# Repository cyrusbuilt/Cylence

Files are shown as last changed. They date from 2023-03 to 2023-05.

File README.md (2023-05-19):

# Cylence


IoT doorbell killswitch (ESP8266 Arduino - Based)

## Synopsis

I have dogs. LOUD dogs. Also, I work from home. Whenever someone comes to my door and rings my doorbell, my dogs go absolutely bonkers and bark their faces off. I've tried training them not to, but to no avail. The problem is, every time I'm in a meeting or a call and my dogs start barking their faces off, it's difficult to get them to stop. So I decided I needed a way to temporarily *mute* my door bell. A sort of "killswitch", if you will. Seems simple enough... Just put a toggle switch or light switch betwen in the power source and the bell transformer. But my bell transformer is in the basement. And what if I forget to turn it back on? Like so many of my IoT projects, I decided it would be a lot cooler if I could just do it from my phone, integrate it with the rest of my home automation system and have alerts to let me know if I forgot to turn it back on. So, I decided to design a simple PCB around an ESP8266 and a relay and then integrate it with [OpenHAB](https://www.openhab.org) and [RedQueen](https://github.com/cyrusbuilt/RedQueen) using [MQTT](https://mqtt.org/). When the Cylence is 'active' it closes the relay (wired to Normally-Closed) which disconnects the power to the bell transformer. Then deactivating shuts off the relay allowing the circuit to close again and power the door bell back up. Easy peasy.

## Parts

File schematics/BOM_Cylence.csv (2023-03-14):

ID | Name | Designator | Footprint | Quantity | Manufacturer Part | Manufacturer | Supplier | Supplier Part | Price
1 | ACT | D1 | PKG-LED-5MM-RED | 1 | L-1503EC | KINGBRIGHT | Element14 | 1003201
2 | NET | D2 | LED-GREEN-2.54-5MM-YUN | 1 | 503UOC
3 | 1N4001 | D3 | DIODE-1N4001 | 1
4 | RS-232 PGM / DBG | H1 | HEADER-MALE-2.54_1X6 | 1
5 | M023.5MM | JP1,JP2 | SCREWTERMINAL-3.5MM-2 | 2
6 | G5LE-14_DC3 | K1 | G5LE-14_SPDT | 1
7 | Huzzah ESP8266 Breakout_TT | U1 | HUZZAH 8266 | 1 |  | Adafruit

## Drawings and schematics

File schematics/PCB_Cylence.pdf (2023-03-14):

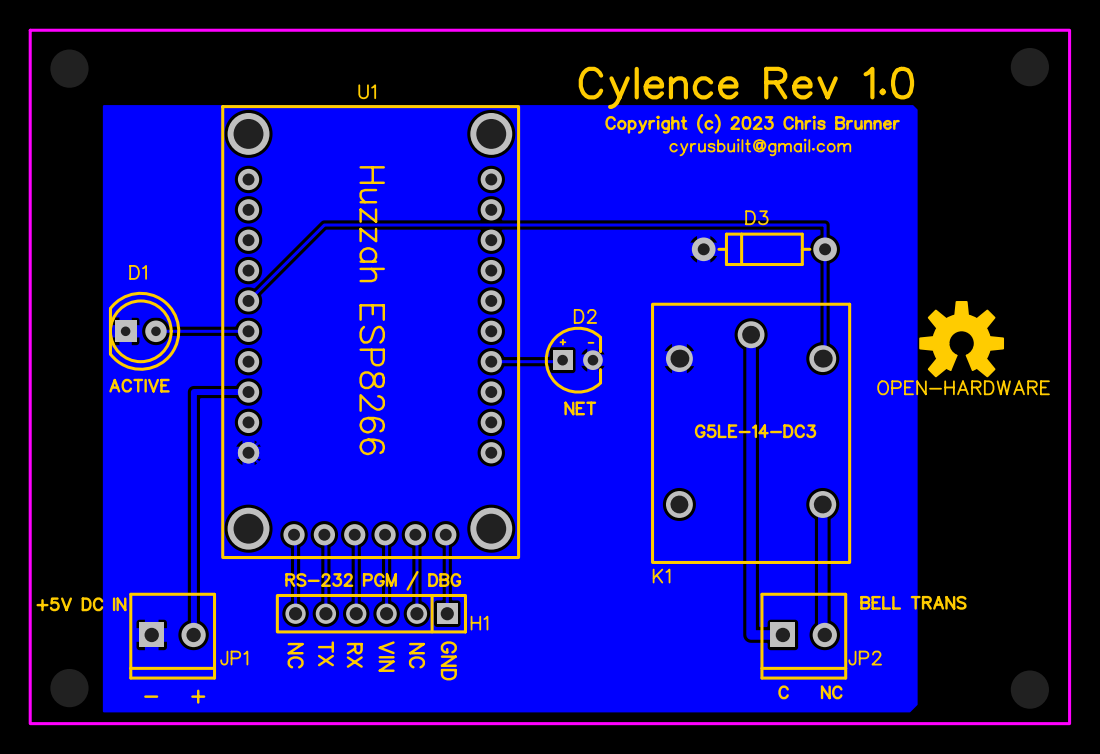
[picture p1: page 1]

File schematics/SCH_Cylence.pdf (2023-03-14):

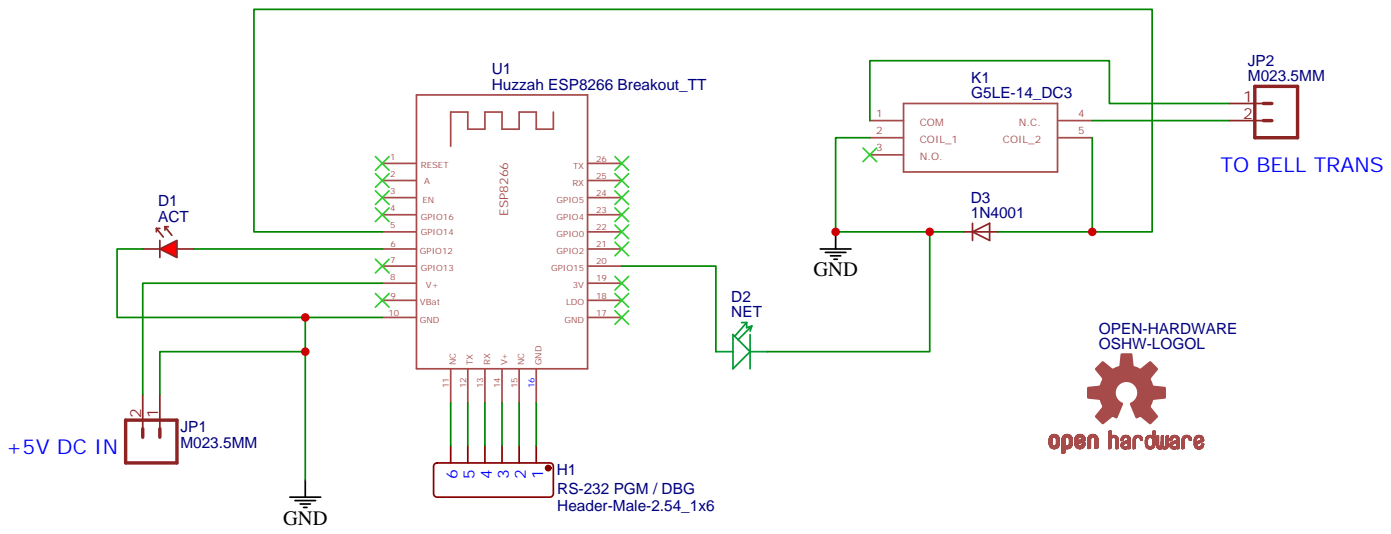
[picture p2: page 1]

Drawn By: Chris Brunner

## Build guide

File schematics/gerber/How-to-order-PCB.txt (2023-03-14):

How to Order PCB

Please refer to:
https://docs.easyeda.com/en/PCB/Order-PCB

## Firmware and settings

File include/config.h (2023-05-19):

#ifndef _CONFIG_H
#define _CONFIG_H

#include <IPAddress.h>

#define DEBUG
#define DEVICE_NAME "CYLENCE"
#define DEVICE_CLASS "cylence"
#define BAUD_RATE 115200
#define ENABLE_OTA
#define ENABLE_MDNS
#define CONFIG_FILE_PATH "/config.json"
#define DEFAULT_SSID "your_ssid_here"
#define DEFAULT_PASSWORD "your_wifi_password"
#define CLOCK_TIMEZONE -4
#define CHECK_WIFI_INTERVAL 30000
#define CLOCK_SYNC_INTERVAL 3600000
#define CHECK_MQTT_INTERVAL 60000 * 5
#define MQTT_TOPIC_STATUS "cylence/status"
#define MQTT_TOPIC_CONTROL "cylence/control"
#define MQTT_TOPIC_DISCOVERY "redqueen/config"
#define MQTT_BROKER "your_mqtt_broker_ip"
#define MQTT_PORT 8883
#ifdef ENABLE_OTA
	#include <ArduinoOTA.h>
	#define OTA_HOST_PORT 8266
	#define OTA_PASSWORD "your_ota_password_here"
#endif
const IPAddress defaultIp(192, 168, 0, 238);
const IPAddress defaultGw(192, 168, 0, 1);
const IPAddress defaultSm(255, 255, 255, 0);
const IPAddress defaultDns(192, 168, 0, 1);

typedef struct {
	// Network stuff
	String hostname;
	String ssid;
	String password;
	IPAddress ip;
	IPAddress gw;
	IPAddress sm;
	IPAddress dns;
	bool useDhcp;

	uint8_t clockTimezone;

	// MQTT stuff
	String mqttTopicStatus;
	String mqttTopicControl;
	String mqttTopicDiscovery;
	String mqttBroker;
	String mqttUsername;
	String mqttPassword;
	uint16_t mqttPort;

	// OTA stuff
	uint16_t otaPort;
	String otaPassword;
} config_t;

#endif

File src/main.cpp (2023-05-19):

#ifndef ESP8266
	#error This firmware is only compatible with ESP8266 controllers.
#endif

#include <Arduino.h>
#include <ESP8266WiFi.h>
#include <WiFiClient.h>
#include <FS.h>
#include <time.h>
#include <TZ.h>
#include "ArduinoJson.h"
#include "Console.h"
#include "ESPCrashMonitor.h"
#include "LED.h"
#include "PubSubClient.h"
#include "Relay.h"
#include "ResetManager.h"
#include "TaskScheduler.h"
#include "TelemetryHelper.h"
#include "config.h"

#define FIRMWARE_VERSION "1.0"

// Pin definitions
#define PIN_LED_ACTIVE 12
#define PIN_LED_NET 15
#define PIN_RELAY 14

// Forward declarations
void onRelayStateChange(RelayInfo *sender);
void onCheckWiFi();
void onCheckMqtt();
void onSyncClock();
void onMqttMessage(char* topic, byte* payload, unsigned int length);

// Global vars
#ifdef ENABLE_MDNS
	#include <ESP8266mDNS.h>
	MDNSResponder mdns;
#endif
WiFiClient wifiClient;
PubSubClient mqttClient(wifiClient);
Task tCheckWiFi(CHECK_WIFI_INTERVAL, TASK_FOREVER, &onCheckWiFi);
Task tCheckMqtt(CHECK_MQTT_INTERVAL, TASK_FOREVER, &onCheckMqtt);
Task tClockSync(CLOCK_SYNC_INTERVAL, TASK_FOREVER, &onSyncClock);
Scheduler taskMan;
HAF_LED activationLED(PIN_LED_ACTIVE, NULL);
HAF_LED netLED(PIN_LED_NET, NULL);
Relay bellRelay(PIN_RELAY, onRelayStateChange, "Killswitch");
config_t config;
bool filesystemMounted = false;
volatile SystemState sysState = SystemState::BOOTING;
volatile bool isActive = false;

String getTimeInfo() {
	time_t now = time(nullptr);
	struct tm *timeinfo = localtime(&now);
	String result = String(asctime(timeinfo));
	result.replace("\n", "");
	return result;
}

void onSyncClock() {
	netLED.on();
	configTime(TZ_America_New_York, "pool.ntp.org");

	Serial.print(F("INIT: Waiting for NTP time sync... "));
	delay(500);
	while (!time(nullptr)) {
		netLED.off();
		ESPCrashMonitor.iAmAlive();
		Serial.print(F("."));
		delay(500);
		netLED.on();
	}

	netLED.off();
	Serial.println(F("DONE"));
	Serial.print(F("INFO: Current time: "));
	Serial.println(getTimeInfo());
}

void publishSystemState() {
	if (!mqttClient.connected()) {
		return;
	}

	netLED.on();

	DynamicJsonDocument doc(400);
	doc["clientId"] = config.hostname.c_str();
	doc["firmwareVersion"] = FIRMWARE_VERSION;
	doc["systemState"] = (uint8_t)sysState;
	doc["silencerState"] = isActive ? "ON" : "OFF";
	doc["lastUpdate"] = getTimeInfo();

	String jsonStr;
	size_t len = serializeJson(doc, jsonStr);
	Serial.print(F("INFO: Publishing system state: "));
	Serial.println(jsonStr);
	if (!mqttClient.publish(config.mqttTopicStatus.c_str(), jsonStr.c_str(), len)) {
		Serial.println(F("ERROR: Failed to publish message."));
	}

	doc.clear();
	netLED.off();
}

void publishDiscoveryPacket() {
	if (!mqttClient.connected()) {
		return;
	}

	DynamicJsonDocument doc(250);
	doc["name"] = config.hostname;
	doc["class"] = DEVICE_CLASS;
	doc["statusTopic"] = config.mqttTopicStatus;
	doc["controlTopic"] = config.mqttTopicControl;

	String jsonStr;
	size_t len = serializeJson(doc, jsonStr);
	Serial.print(F("INFO: Publishing discovery packet: "));
	Serial.println(jsonStr);
	if (!mqttClient.publish(config.mqttTopicDiscovery.c_str(), jsonStr.c_str(), len)) {
		Serial.println(F("ERROR: Failed to publish message."));
	}

	doc.clear();
	netLED.off();
}

void onRelayStateChange(RelayInfo *sender) {
	isActive = sender->state == RelayState::RelayClosed;
	activationLED.setState(isActive ? LEDState::LED_On : LEDState::LED_Off);
	publishSystemState();
}

void resumeNormal() {
	Serial.println(F("INFO: Resuming normal operation..."));
	taskMan.enableAll();
	netLED.off();
	sysState = SystemState::NORMAL;
	publishSystemState();
}

void printNetworkInfo() {
	Serial.print(F("INFO: Local IP: "));
	Serial.println(WiFi.localIP());
	Serial.print(F("INFO: Gateway: "));
	Serial.println(WiFi.gatewayIP());
	Serial.print(F("INFO: Subnet mask: "));
	Serial.println(WiFi.subnetMask());
	Serial.print(F("INFO: DNS server: "));
	Serial.println(WiFi.dnsIP());
	Serial.print(F("INFO: MAC address: "));
	Serial.println(WiFi.macAddress());
	#ifdef DEBUG
		WiFi.printDiag(Serial);
	#endif
}

void reboot() {
	Serial.println(F("INFO: Rebooting..."));
	Serial.flush();
	delay(1000);
	ResetManager.softReset();
}

void saveConfiguration() {
	Serial.print(F("INFO: Saving configuration to: "));
	Serial.print(CONFIG_FILE_PATH);
	Serial.println(F(" ... "));
	if (!filesystemMounted) {
		Serial.println(F("FAIL"));
		Serial.println(F("ERROR: Filesystem not mounted."));
		return;
	}

	DynamicJsonDocument doc(400);
	doc["hostname"] = config.hostname;
	doc["useDhcp"] = config.useDhcp;
	IPAddress ipAddr = IPAddress(config.ip);
	doc["ip"] = ipAddr.toString();
	ipAddr = IPAddress(config.gw);
	doc["gateway"] = ipAddr.toString();
	ipAddr = IPAddress(config.sm);
	doc["subnetmask"] = ipAddr.toString();
	ipAddr = IPAddress(config.dns);
	doc["dnsServer"] = ipAddr.toString();
	doc["wifiSSID"] = config.ssid;
	doc["wifiPassword"] = config.password;
	doc["timezone"] = config.clockTimezone;
	doc["mqttBroker"] = config.mqttBroker;
	doc["mqttPort"] = config.mqttPort;
	doc["mqttControlTopic"] = config.mqttTopicControl;
	doc["mqttStatusTopic"] = config.mqttTopicStatus;
	doc["mqttDiscoveryTopic"] = config.mqttTopicDiscovery;
	doc["mqttUsername"] = config.mqttUsername;
	doc["mqttPassword"] = config.mqttPassword;
	#ifdef ENABLE_OTA
		doc["otaPort"] = config.otaPort;
		doc["otaPassword"] = config.otaPassword;
	#endif

	File configFile = SPIFFS.open(CONFIG_FILE_PATH, "w");
	if (!configFile) {
		Serial.println(F("FAIL"));
		Serial.println(F("ERROR: Failed to open config file for writing."));
		doc.clear();
		return;
	}

	serializeJsonPretty(doc, configFile);
	doc.clear();
	configFile.flush();
	configFile.close();
	Serial.println(F("DONE"));
}

void printWarningAndContinue(const __FlashStringHelper *message) {
	Serial.println();
	Serial.println(message);
	Serial.println(F("INFO: Continuing... "));
}

void setConfigurationDefaults() {
	String chipId = String(ESP.getChipId(), HEX);
	String defHostname = String(DEVICE_NAME) + "_" + chipId;

	config.hostname = defHostname;
	config.ip = defaultIp;
	config.mqttBroker = MQTT_BROKER;
	config.mqttPassword = "";
	config.mqttPort = MQTT_PORT;
	config.mqttTopicControl = MQTT_TOPIC_CONTROL;
	config.mqttTopicStatus = MQTT_TOPIC_STATUS;
	config.mqttTopicDiscovery = MQTT_TOPIC_DISCOVERY;
	config.mqttUsername = "";
	config.password = DEFAULT_PASSWORD;
	config.sm = defaultSm;
	config.ssid = DEFAULT_SSID;
	config.useDhcp = false;
	config.clockTimezone = CLOCK_TIMEZONE;
	config.dns = defaultDns;
	config.gw = defaultGw;
	
	#ifdef ENABLE_OTA
		config.otaPort = config.otaPort;
		config.otaPassword = config.otaPassword;
	#endif
}

void loadConfiguration() {
	memset(&config, 0, sizeof(config));

	Serial.print(F("INFO: Loading config file "));
	Serial.print(CONFIG_FILE_PATH);
	Serial.print(F(" ... "));
	if (!filesystemMounted) {
		Serial.println(F("FAIL"));
		Serial.println(F("ERROR: Filesystem not mounted."));
		return;
	}

	if (!SPIFFS.exists(CONFIG_FILE_PATH)) {
		Serial.println(F("FAIL"));
		Serial.println(F("WARN: Config file does not exist. Creating with default config... "));
		saveConfiguration();
		return;
	}

	File configFile = SPIFFS.open(CONFIG_FILE_PATH, "r");
	if (!configFile) {
		Serial.println(F("FAIL"));
		Serial.println(F("ERROR: Unable to open config file. Using default config."));
		return;
	}

	size_t size = configFile.size();
	uint16_t freeMem = ESP.getMaxFreeBlockSize() - 512;
	if (size > freeMem) {
		Serial.println(F("FAIL"));
		Serial.print(F("ERROR: Not enough free memory to load document. Size = "));
		Serial.print(size);
		Serial.print(F(", Free = "));
		Serial.println(freeMem);
		configFile.close();
		return;
	}

	DynamicJsonDocument doc(freeMem);
	DeserializationError error = deserializeJson(doc, configFile);
	if (error) {
		Serial.println(F("FAIL"));
		Serial.println(F("ERROR: Failed to parse config file to JSON. Using default config."));
		configFile.close();
		return;
	}

	doc.shrinkToFit();
	configFile.close();

	String chipId = String(ESP.getChipId(), HEX);
	String defHostname = String(DEVICE_NAME) + "_" + chipId;

	config.hostname = doc.containsKey("hostname") ? doc["hostname"].as<String>() : defHostname;
	config.useDhcp = doc.containsKey("isDhcp") ? doc["isDhcp"].as<bool>() : false;

	if (doc.containsKey("ip")) {
		if (!config.ip.fromString(doc["ip"].as<String>())) {
			printWarningAndContinue(F("WARN: Invalid IP in configuration. Falling back to factory default."));
		}
	}
	else {
		config.ip = defaultIp;
	}

	if (doc.containsKey("gateway")) {
		if (!config.gw.fromString(doc["gateway"].as<String>())) {
			printWarningAndContinue(F("WARN: Invalid gateway in configuration. Falling back to factory default."));
		}
	}
	else {
		config.gw = defaultGw;
	}

	if (doc.containsKey("subnetmask")) {
		if (!config.sm.fromString(doc["subnetmask"].as<String>())) {
			printWarningAndContinue(F("WARN: Invalid subnet mask in configuration. Falling back to factory default."));
		}
	}
	else {
		config.sm = defaultSm;
	}

	if (doc.containsKey("dnsServer")) {
		if (!config.dns.fromString(doc["dnsServer"].as<String>())) {
			printWarningAndContinue(F("WARN: Invalid DNS IP in configuration. Falling back to factory default."));
		}
	}
	else {
		config.dns = defaultDns;
	}

	config.ssid = doc.containsKey("wifiSSID") ? doc["wifiSSID"].as<String>() : DEFAULT_SSID;
	config.password = doc.containsKey("wifiPassword") ? doc["wifiPassword"].as<String>() : DEFAULT_PASSWORD;
	config.clockTimezone = doc.containsKey("timezone") ? doc["timezone"].as<uint8_t>() : CLOCK_TIMEZONE;
	config.mqttBroker = doc.containsKey("mqttBroker") ? doc["mqttBroker"].as<String>() : MQTT_BROKER;
	config.mqttPort = doc.containsKey("mqttPort") ? doc["mqttPort"].as<int>() : MQTT_PORT;
	config.mqttTopicControl = doc.containsKey("mqttControlTopic") ? doc["mqttControlTopic"].as<String>() : MQTT_TOPIC_CONTROL;
	config.mqttTopicStatus = doc.containsKey("mqttStatusTopic") ? doc["mqttStatusTopic"].as<String>() : MQTT_TOPIC_STATUS;
	config.mqttTopicDiscovery = doc.containsKey("mqttDiscoveryTopic") ? doc["mqttDiscoveryTopic"].as<String>() : MQTT_TOPIC_DISCOVERY;
	config.mqttUsername = doc.containsKey("mqttUsername") ? doc["mqttUsername"].as<String>() : "";
	config.mqttPassword = doc.containsKey("mqttPassword") ? doc["mqttPassword"].as<String>() : "";

	#ifdef ENABLE_OTA
		config.otaPort = doc.containsKey("otaPort") ? doc["otaPort"].as<uint16_t>() : OTA_HOST_PORT;
		config.otaPassword = doc.containsKey("otaPassword") ? doc["otaPassword"].as<String>() : OTA_PASSWORD;
	#endif

	doc.clear();
	Serial.println(F("DONE"));
}

void doFactoryRestore() {
	Serial.println();
	Serial.println(F("Are you sure you wish to restore to factory defaults? (Y/n)"));
	Console.waitForUserInput();

	String str = Console.getInputString();
	str.toLowerCase();
	if (str == "y") {
		Serial.print(F("INFO: Clearing current config... "));
		if (filesystemMounted) {
			if (SPIFFS.remove(CONFIG_FILE_PATH)) {
				Serial.println(F("DONE"));
				Serial.print(F("INFO: Removed file: "));
				Serial.println(CONFIG_FILE_PATH);

				Serial.print(F("INFO: Rebooting in "));
				for (uint8_t i = 5; i >= 1; i--) {
					Serial.print(i);
					Serial.print(F(" "));
					delay(1000);
				}

				reboot();
			}
			else {
				Serial.println(F("FAIL"));
				Serial.println(F("ERROR: Failed to delete configuration file."));
			}
		}
		else {
			Serial.println(F("FAIL"));
			Serial.println(F("ERROR: Filesystem not mounted."));
		}
	}

	Serial.println();
}

void printAvailableNetworks() {
	ESPCrashMonitor.defer();
	Serial.println(F("INFO: Scanning WiFi networks... "));
	int numNetworks = WiFi.scanNetworks();
	for (int i = 0; i < numNetworks; i++) {
		Serial.print(F("ID: "));
		Serial.print(i);
		Serial.print(F("\tNetwork name: "));
		Serial.print(WiFi.SSID());
		Serial.print(F("\tSignal strength: "));
		Serial.println(WiFi.RSSI());
	}

	Serial.println(F("----------------------------------"));
}

bool reconnectMqttClient() {
	if (mqttClient.connected()) {
		return true;
	}

	netLED.on();
	Serial.print(F("INFO: Attempting to establish MQTT connection to "));
	Serial.print(config.mqttBroker);
	Serial.print(F(" on port "));
	Serial.print(config.mqttPort);
	Serial.println(F(" ... "));
	
	bool didConnect = false;
	if (config.mqttUsername.length() > 0 && config.mqttPassword.length() > 0) {
		didConnect = mqttClient.connect(config.hostname.c_str(), config.mqttUsername.c_str(), config.mqttPassword.c_str());
	}
	else {
		didConnect = mqttClient.connect(config.hostname.c_str());
	}

	if (didConnect) {
		Serial.print(F("INFO: Subscribing to topic: "));
		Serial.println(config.mqttTopicControl);
		mqttClient.subscribe(config.mqttTopicControl.c_str());

		Serial.print(F("INFO: Publishing to topic: "));
		Serial.println(config.mqttTopicStatus);

		Serial.print(F("INFO: Discovery topic: "));
		Serial.println(config.mqttTopicDiscovery);
	}
	else {
		String failReason = TelemetryHelper::getMqttStateDesc(mqttClient.state());
		Serial.print(F("ERROR: Failed to connect to MQTT broker: "));
		Serial.println(failReason);
	}

	netLED.off();
	return didConnect;
}

void onCheckMqtt() {
	Serial.println(F("INFO: Checking MQTT connection status... "));
	if (reconnectMqttClient()) {
		Serial.println(F("INFO: Successfully reconnected to MQTT broker."));
		publishSystemState();
		publishDiscoveryPacket();
	}
	else {
		Serial.println(F("ERROR: MQTT connection lost and reconnect failed."));
		Serial.print(F("INFO: Retrying connection in "));
		Serial.print(CHECK_MQTT_INTERVAL % 1000);
		Serial.println(F(" seconds ..."));
	}
}

void activate() {
	Serial.println(F("INFO: Killswitch active."));
	bellRelay.close();
}

void deactivate() {
	Serial.println(F("INFO: Killswitch deactivated."));
	bellRelay.open();
}

void handleControlRequest(ControlCommand cmd) {
	if (sysState == SystemState::DISABLED && cmd != ControlCommand::ENABLE) {
		// THOU SHALT NOT PASS!!!
		// We can't process this command because we are disabled.
		Serial.print(F("WARN: Ignoring command "));
		Serial.print((uint8_t)cmd);
		Serial.println(F(" because the system is currently disabled."));
		return;
	}

	switch (cmd) {
		case ControlCommand::ENABLE:
			Serial.println(F("INFO: Enabling system."));
			sysState = SystemState::NORMAL;
			break;
		case ControlCommand::DISABLE:
			Serial.println(F("WARN: Disabling system."));
			sysState = SystemState::DISABLED;
			break;
		case ControlCommand::REBOOT:
			reboot();
			break;
		case ControlCommand::REQUEST_STATUS:
			break;
		case ControlCommand::ACTIVATE:
			isActive ? deactivate() : activate();
			break;
		default:
			Serial.print(F("WARN: Unknown command: "));
			Serial.println((uint8_t)cmd);
			break;
	}

	publishSystemState();
}

void onMqttMessage(char* topic, byte* payload, unsigned int length) {
	Serial.print(F("INFO: [MQTT] Message arrived: ["));
	Serial.print(topic);
	Serial.print(F("] "));

	// It's a lot easier to deal with if we just convert the payload
	// to a string first.
	String msg;
	for (unsigned int i = 0; i < length; i++) {
		msg += (char)payload[i];
	}

	Serial.println(msg);

	DynamicJsonDocument doc(100);
	DeserializationError error = deserializeJson(doc, msg.c_str());
	if (error) {
		Serial.print(F("ERROR: Failed to parse MQTT message to JSON: "));
		Serial.println(error.c_str());
		doc.clear();
		return;
	}

	if (doc.containsKey("clientId")) {
		String id = doc["clientId"].as<String>();
		id.toUpperCase();
		if (!id.equals(config.hostname)) {
			Serial.println(F("WARN: Control message not intended for this host. Ignoring..."));
			doc.clear();
			return;
		}
	}
	else {
		Serial.println(F("WARN: MQTT message does not contain client ID. Ignoring..."));
		doc.clear();
		return;
	}

	if (!doc.containsKey("command")) {
		Serial.println(F("WARN: MQTT message does not contain a control command. Ignoring..."));
		doc.clear();
		return;
	}

	// When system is in the "disabled" state, the only command it will accept
	// is "enable". All other commands are ignored.
	ControlCommand cmd = (ControlCommand)doc["command"].as<uint8_t>();

	doc.clear();
	handleControlRequest(cmd);
}

void failSafe() {
	sysState = SystemState::DISABLED;
	publishSystemState();
	ESPCrashMonitor.defer();
	Serial.println();
	Serial.println(F("ERROR: Entering failsafe (config) mode..."));
	taskMan.disableAll();
	netLED.on();
	Console.enterCommandInterpreter();
}

void initMDNS() {
	#ifdef ENABLE_MDNS
		Serial.print(F("INIT: Starting MDNS responder..."));
		if (WiFi.status() == WL_CONNECTED) {
			ESPCrashMonitor.defer();
			delay(500);

			if (!mdns.begin(config.hostname)) {
				Serial.println(F(" FAILED"));
				return;
			}

			#ifdef ENABLE_OTA
				bool authUpload = config.otaPassword.length() > 0;
				mdns.enableArduino(config.otaPort, authUpload);
			#endif
			Serial.println(F(" DONE"));
		}
		else {
			Serial.println(F(" FAILED"));
		}
	#endif
}

void initFilesystem() {
	Serial.print(F("INIT: Initializing SPIFFS and mounting filesystem... "));
	if (!SPIFFS.begin()) {
		Serial.println(F("FAIL"));
		Serial.println(F("ERROR: Unable to mount filesystem."));
		return;
	}

	filesystemMounted = true;
	Serial.println(F("DONE"));
	setConfigurationDefaults();
	loadConfiguration();
}

void initMQTT() {
	Serial.print(F("INIT: Initializing MQTT client... "));
	mqttClient.setServer(config.mqttBroker.c_str(), config.mqttPort);
	mqttClient.setCallback(onMqttMessage);
	mqttClient.setBufferSize(500);
	Serial.println(F("DONE"));
	if (reconnectMqttClient()) {
		delay(500);
		publishSystemState();
	}
}

void connectWiFi() {
	if (config.hostname) {
		WiFi.hostname(config.hostname.c_str());
	}

	Serial.println(F("DEBUG: Setting mode..."));
	WiFi.mode(WIFI_STA);
	Serial.println(F("DEBUG: Disconnect and clear to prevent auto connect..."));
	WiFi.persistent(false);
	WiFi.disconnect(true);
	ESPCrashMonitor.defer();

	delay(1000);
	if (config.useDhcp) {
		WiFi.config(0U, 0U, 0U, 0U);
	}
	else {
		WiFi.config(config.ip, config.gw, config.sm, config.dns);
	}

	Serial.println(F("DEBUG: Beginning connection..."));
	WiFi.begin(config.ssid, config.password);
	Serial.println(F("DEBUG: Waiting for connection..."));

	const uint8_t maxTries = 20;
	uint8_t currentTry = 0;
	while ((WiFi.status() != WL_CONNECTED) && (currentTry < maxTries)) {
		ESPCrashMonitor.iAmAlive();
		currentTry++;
		netLED.blink(500);
		delay(500);
	}

	if (WiFi.status() != WL_CONNECTED) {
		// Connection failed. May the AP went down? Let's try again later.
		Serial.println(F("ERROR: Failed to connect to WiFi!"));
		Serial.println(F("WARN: Will attempt to reconnect at scheduled interval."));
	}
	else {
		printNetworkInfo();
	}
}

void initWiFi() {
	Serial.println(F("INIT: Initializing WiFi..."));
	printAvailableNetworks();

	Serial.print(F("INFO: Connecting to SSID: "));
	Serial.print(config.ssid);
	Serial.print(F("..."));

	connectWiFi();
}

void initOTA() {
	#ifdef ENABLE_OTA
		Serial.print(F("INIT: Starting OTA updater... "));
		if (WiFi.status() == WL_CONNECTED) {
			ArduinoOTA.setPort(config.otaPort);
			ArduinoOTA.setHostname(config.hostname.c_str());
			ArduinoOTA.setPassword(config.otaPassword.c_str());
			ArduinoOTA.onStart([]() {
				// Handle start of OTA update. Determines update type.
				String type;
				if (ArduinoOTA.getCommand() == U_FLASH) {
					type = "sketch";
				}
				else {
					type = "filesystem";
				}

				sysState = SystemState::UPDATING;
				publishSystemState();
				Serial.println("INFO: Starting OTA update (type: " + type + ") ...");
			});
			ArduinoOTA.onEnd([]() {
				// Handles update completion.
				Serial.println(F("INFO: OTA updater stopped."));
			});
			ArduinoOTA.onProgress([](unsigned int progress, unsigned int total) {
				// Reports update progress.
				netLED.blink(100);
				ESPCrashMonitor.iAmAlive();
				Serial.printf("INFO: OTA Update Progress: %u%%\r", (progress / (total / 100)));
			});
			ArduinoOTA.onError([](ota_error_t error) {
				// Handles OTA update errors.
				Serial.printf("ERROR: OTA update error [%u]: ", error);
				switch (error) {
					case OTA_AUTH_ERROR:
						Serial.println(F("Auth failed."));
						break;
					case OTA_BEGIN_ERROR:
						Serial.println(F("Begin failed."));
						break;
					case OTA_CONNECT_ERROR:
						Serial.println(F("Connect failed."));
						break;
					case OTA_RECEIVE_ERROR:
						Serial.println(F("Receive failed."));
						break;
					case OTA_END_ERROR:
						Serial.println(F("End failed."));
						break;
					default:
						break;
				}
			});
			ArduinoOTA.begin();
			Serial.println(F("DONE"));
		}
		else {
			Serial.println(F("FAIL"));
		}
	#endif
}

void onCheckWiFi() {
	Serial.println(F("INFO: Checking WiFi connectivity..."));
	if (WiFi.status() != WL_CONNECTED) {
		Serial.println(F("WARN: Lost connection. Attempting reconnect..."));
		connectWiFi();
		if (WiFi.status() == WL_CONNECTED) {
			initMDNS();
			initMQTT();
		}
	}
}

void initSerial() {
	Serial.begin(BAUD_RATE);
	#ifdef DEBUG
		const bool debug = true;
	#else
		const bool debug = false;
	#endif
	Serial.setDebugOutput(debug);
	Serial.println();
	Serial.print(F("Cylence v"));
	Serial.print(FIRMWARE_VERSION);
	Serial.println(F(" booting..."));
}

void initOutputs() {
	Serial.print(F("INIT: Initializing outputs... "));
	activationLED.init();
	activationLED.on();
	netLED.init();
	netLED.on();
	bellRelay.init();
	bellRelay.open();
	Serial.println(F("DONE"));
}

void handleNewHostname(const char* newHostname) {
	if (strcmp(newHostname, config.hostname.c_str()) == 0) {
		config.hostname = newHostname;
		initMDNS();
	}
}

void handleSwitchToDhcp() {
	if (config.useDhcp) {
		Serial.println(F("INFO: DHCP mode already set. Skipping..."));
		Serial.println();
	}
	else {
		config.useDhcp = true;
		Serial.println(F("INFO: Set DHCP mode."));
		WiFi.config(0U, 0U, 0U, 0U);
	}
}
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
void loop() {
	ESPCrashMonitor.iAmAlive();
	Console.checkInterrupt();
	taskMan.execute();
	#ifdef ENABLE_MDNS
		mdns.update();
	#endif
	#ifdef ENABLE_OTA
		ArduinoOTA.handle();
	#endif
	mqttClient.loop();
}
